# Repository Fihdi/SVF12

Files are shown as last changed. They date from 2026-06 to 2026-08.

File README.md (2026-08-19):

# 8hp 12dB/Oct Voltage Controlled state-variable Filter

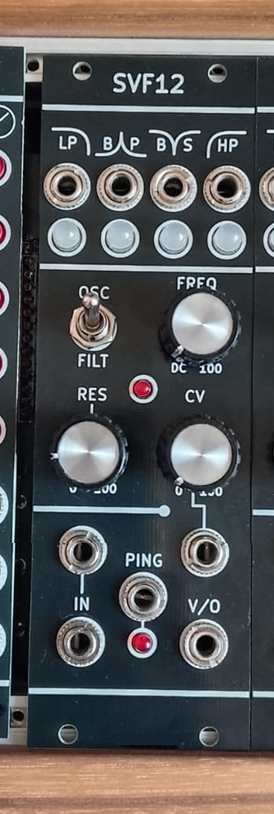
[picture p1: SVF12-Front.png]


# Features
- Two  Inputs **IN** (DC-coupled, allows for audio and CV processing)
- Volt per octave Input **V/O**
- Ping Input **PING**
- Self-Resonance switch **FILT/OSC**
- Lowpass **LP** Bandpass **BP** Bandstop(Notch) **BS** and Highpass **HP** outputs 

# Oscillator mode
The module can be switched from Filter mode (Switch in the **FILT** position) to Oscillator mode (Switch in the **OSC** position), turning the module into a musical sine-cosine quadrature VCO. This can produce clean sine waves on the **BP**, **BS** and **LP** outputs with no input, a mode called self-oscillation. The sinusoidal signals of  **BP** and **HP** are phase-shifted 0, 90 and 180 degrees.

.Inverting the **BP** signal and sending it back into a state variable filter it starts to self-oscillate, albeit with no limiting. Switching from **FILT** to **OSC** changes the **RES** knob from a variable voltage divider to an attenuverter with diode-clipping. With a trimmer on the back of the module, the **V/O** input can be tuned to allow for volt per octave tracking

# Ping Input
By sending a rising-edge signal like a Gate or a short Pulse to the **PING** input, the filter core gets excited and creates a damped oscillation. The length of this oscillation is controlled by the resonance (**RES**) setting.

# Power
A standard 10-pin Eurorack power connector is used (Red Stripe indicates -12V (negative twelve volts)). The module is internally running on +/-9V to stabilise the volt per octave tracking.

# Sponsor
A big Thank You to [PCBWay](https://www.pcbway.com) for sponsoring the development and prototyping of this module! They have excellent build quality and I can recommend using their service to build your own projects! I used the "Black" soldermask and white silkscreen and the surface has very deep and glossy black finish.

Simply upload the Gerber and production files for the B-Board and 90% of the circuitry is done. Solder the final through-hole components and tightend the screws and you have a finished Eurorack module, ready to give your sounds a crunchy filter effect.



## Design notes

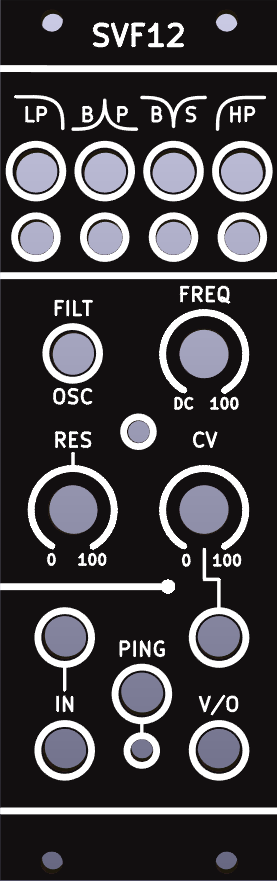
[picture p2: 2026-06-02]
SVF12Front.png

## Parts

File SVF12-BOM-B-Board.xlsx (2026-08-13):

 |  |  | SVF12 B-Board BOM
Item # | *Designator | *Qty | Manufacturer | *Mfg Part # | Description / Value | *Package/Footprint | Type | Your Instructions / Notes
1 | C1,C2 | 2 |  | C107193 | 220pF | Capacitor_SMD:C_1206_3216Metric
2 | C3,C5 | 2 |  | C309030 | 100n | Capacitor_SMD:C_1206_3216Metric
3 | C7 | 1 |  | C5137623 | 10n | Capacitor_SMD:C_1206_3216Metric
4 | C101,C102,C103,C104 | 4 |  | C9807 | 10u | Capacitor_SMD:C_1206_3216Metric
5 | D2,D3,D4 | 3 |  | C917117 | 1N4148 | Diode_SMD:D_SOD-323_HandSoldering
6 | D5,D6 | 2 |  |  | LED | LED_THT:LED_D3.0mm |  | DNP
7 | J2 | 1 |  |  | Conn_02x05_Odd_Even | Connector_IDC:IDC-Header_2x05_P2.54mm_Vertical |  | DNP
8 | J101 | 1 |  |  | Conn_01x09_Pin | Connector_PinHeader_2.54mm:PinHeader_1x09_P2.54mm_Vertical |  | DNP
9 | J104 | 1 |  |  | Conn_01x08_Pin | Connector_PinSocket_2.54mm:PinSocket_1x08_P2.54mm_Vertical |  | DNP
10 | Q1,Q2 | 2 |  | C148244 | BC857 | Package_TO_SOT_SMD:SOT-23-3
11 | Q3 | 1 |  | C475630 | BC847 | Package_TO_SOT_SMD:SOT-23
12 | R1,R4,R5,R6,R7,R8,R10,R14,R16,R18,R28,R29,R31,R34,R35,R42 | 16 |  | C2907421 | 100k | Resistor_SMD:R_1206_3216Metric
13 | R9,R19 | 2 |  | C706444 | 200k | Resistor_SMD:R_1206_3216Metric
14 | R11,R17,R21,R32,R33,R101,R104 | 7 |  | C131398 | 1k | Resistor_SMD:R_1206_3216Metric
15 | R12,R15,R22 | 3 |  | C2930413 | 2k2 | Resistor_SMD:R_1206_3216Metric
16 | R20 | 1 |  | C2907423 | 10k | Resistor_SMD:R_1206_3216Metric
17 | R23 | 1 |  | C2907507 | 47k | Resistor_SMD:R_1206_3216Metric
18 | R102,R103 | 2 |  | C4299795 | 6k2 | Resistor_SMD:R_1206_3216Metric
19 | RV4 | 1 |  |  | 100k | Potentiometer_THT:Potentiometer_Bourns_3296W_Vertical |  | DNP
20 | U1,U4 | 2 |  | C12594 | TL074 | Package_SO:SOIC-14_3.9x8.7mm_P1.27mm
21 | U5 | 1 |  | C174050 | LM13700 | Package_SO:SOIC-16_3.9x9.9mm_P1.27mm
22 | U101 | 1 |  | C51466 | LM317_SOT-223 | Package_TO_SOT_SMD:SOT-223-3_TabPin2
23 | U102 | 1 |  | C19267471 | LM337_SOT223 | Package_TO_SOT_SMD:SOT-223-3_TabPin2

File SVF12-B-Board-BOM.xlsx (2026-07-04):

 |  |  | SVF12 B-Board BOM
Item # | *Designator | *Qty | Manufacturer | *Mfg Part # | Description / Value | *Package/Footprint | Type | Your Instructions / Notes
1 | C1,C2 | 2 |  | C113905 | 220pF | Capacitor_SMD:C_1206_3216Metric
2 | C3,C4,C5 | 3 |  | C82601 | 100n | Capacitor_SMD:C_1206_3216Metric
3 | C7 | 1 |  | C107192 | 10n | Capacitor_SMD:C_1206_3216Metric
4 | C101,C102,C103,C104 | 4 |  | C9807 | 10u | Capacitor_SMD:C_1206_3216Metric
5 | D2,D3,D4 | 3 |  | C917117 | 1N4148 | Diode_SMD:D_SOD-323_HandSoldering
6 | D5,D6 | 2 |  |  | LED | LED_THT:LED_D3.0mm |  | DNP
7 | J2 | 1 |  |  | Conn_02x05_Odd_Even | Connector_IDC:IDC-Header_2x05_P2.54mm_Vertical |  | DNP
8 | J101 | 1 |  |  | Conn_01x08_Pin | Connector_PinSocket_2.54mm:PinSocket_1x08_P2.54mm_Vertical |  | DNP
9 | J103 | 1 |  |  | Conn_01x09_Pin | Connector_PinHeader_2.54mm:PinHeader_1x09_P2.54mm_Vertical |  | DNP
10 | Q1,Q2 | 2 |  | C148244 | BC857 | Package_TO_SOT_SMD:SOT-23-3
11 | Q3 | 1 |  | C475630 | BC847 | Package_TO_SOT_SMD:SOT-23
12 | R1,R4,R5,R6,R7,R8,R10,R14,R16,R18,R28,R29,R31,R34,R35,R42 | 16 |  | C728669 | 100k | Resistor_SMD:R_1206_3216Metric
13 | R9,R19 | 2 |  | C2907451 | 200k | Resistor_SMD:R_1206_3216Metric
14 | R11,R17,R21,R32,R33,R101,R104 | 7 |  | C131398 | 1k | Resistor_SMD:R_1206_3216Metric
15 | R12,R15,R22 | 3 |  | C2907443 | 2k2 | Resistor_SMD:R_1206_3216Metric
16 | R20 | 1 |  | C136889 | 10k | Resistor_SMD:R_1206_3216Metric
17 | R23 | 1 |  | C870758 | 47k | Resistor_SMD:R_1206_3216Metric
18 | R102,R103 | 2 |  | C4299795 | 6k2 | Resistor_SMD:R_1206_3216Metric
19 | RV4 | 1 |  |  | 100k | Potentiometer_THT:Potentiometer_Bourns_3296W_Vertical |  | DNP
20 | U1,U3,U4 | 3 |  | C12594 | TL074 | Package_SO:SOIC-14_3.9x8.7mm_P1.27mm
21 | U5 | 1 |  | C174050 | LM13700 | Package_SO:SOIC-16_3.9x9.9mm_P1.27mm
22 | U101 | 1 |  | C51466 | LM317_SOT-223 | Package_TO_SOT_SMD:SOT-223-3_TabPin2
23 | U102 | 1 |  | C19267471 | LM337_SOT223 | Package_TO_SOT_SMD:SOT-223-3_TabPin2
Need a quick and accurante quote? Need an efficient production? Please read SMT Ordering Necessary Files & Info in 1 minute. Thank you very much!
Click for Instructions on How to Create a BOM (https://www.pcbway.com/blog/PCB_Assembly/How_to_Build_a_BOM__Bill_Of_Materials_.html)

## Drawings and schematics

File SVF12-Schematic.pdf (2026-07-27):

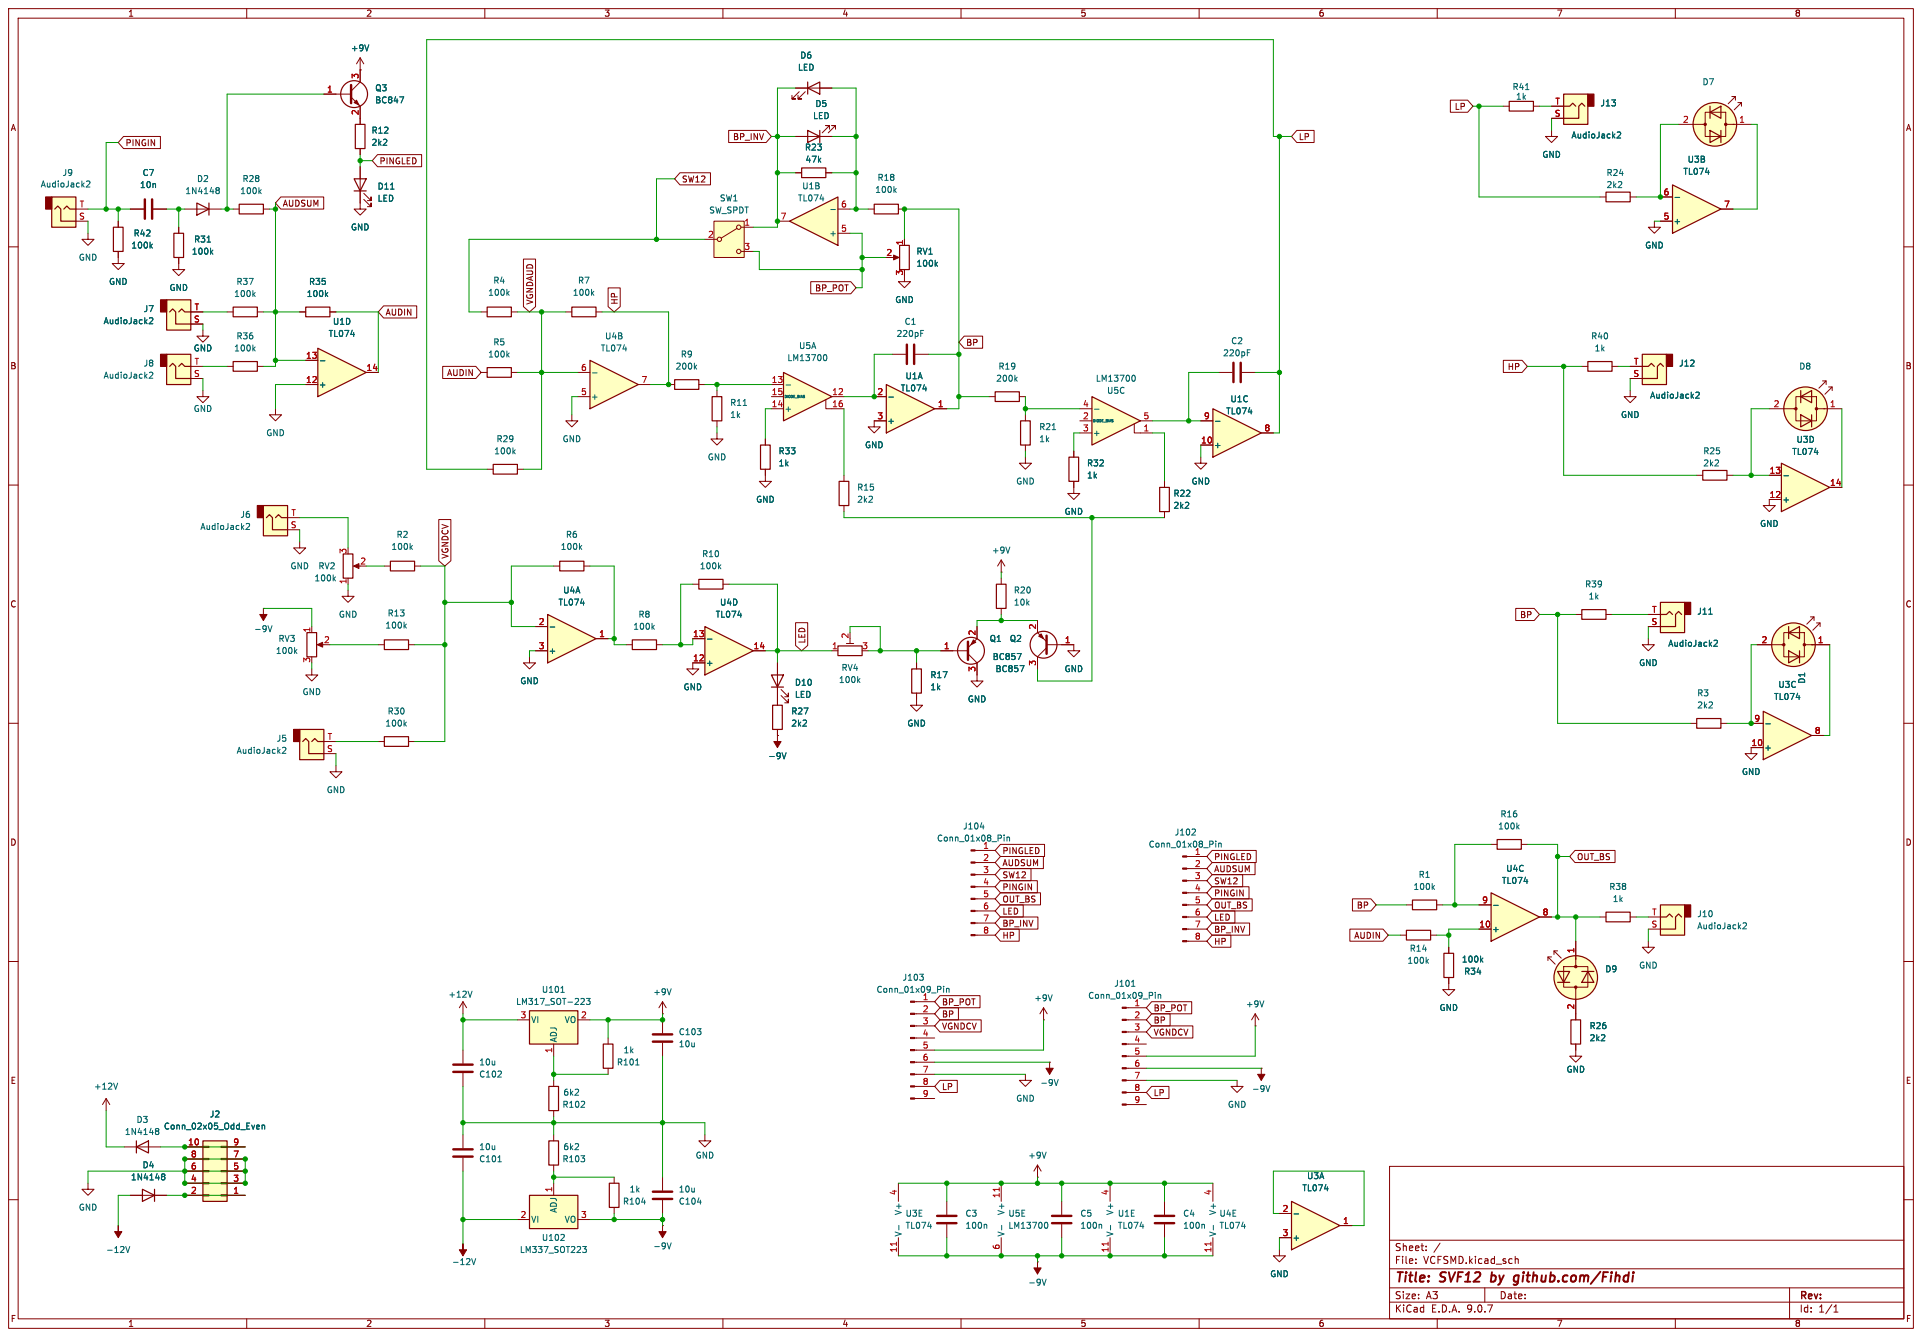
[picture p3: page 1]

Id: 1/1 Title: SVF12 by github.com/Fihdi File: VCFSMD.kicad_sch Sheet: / GND

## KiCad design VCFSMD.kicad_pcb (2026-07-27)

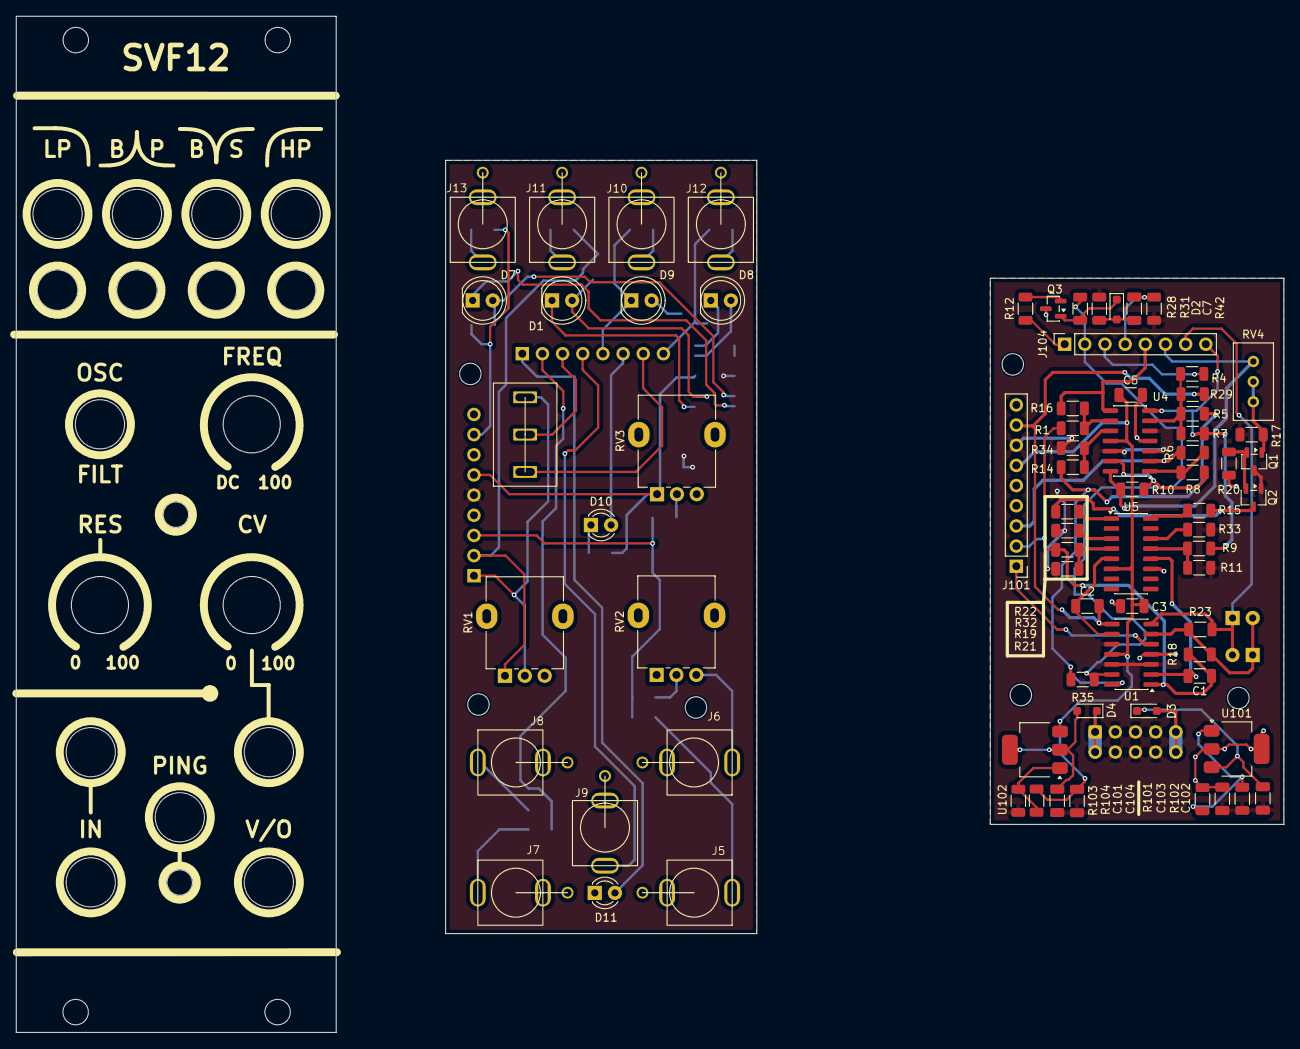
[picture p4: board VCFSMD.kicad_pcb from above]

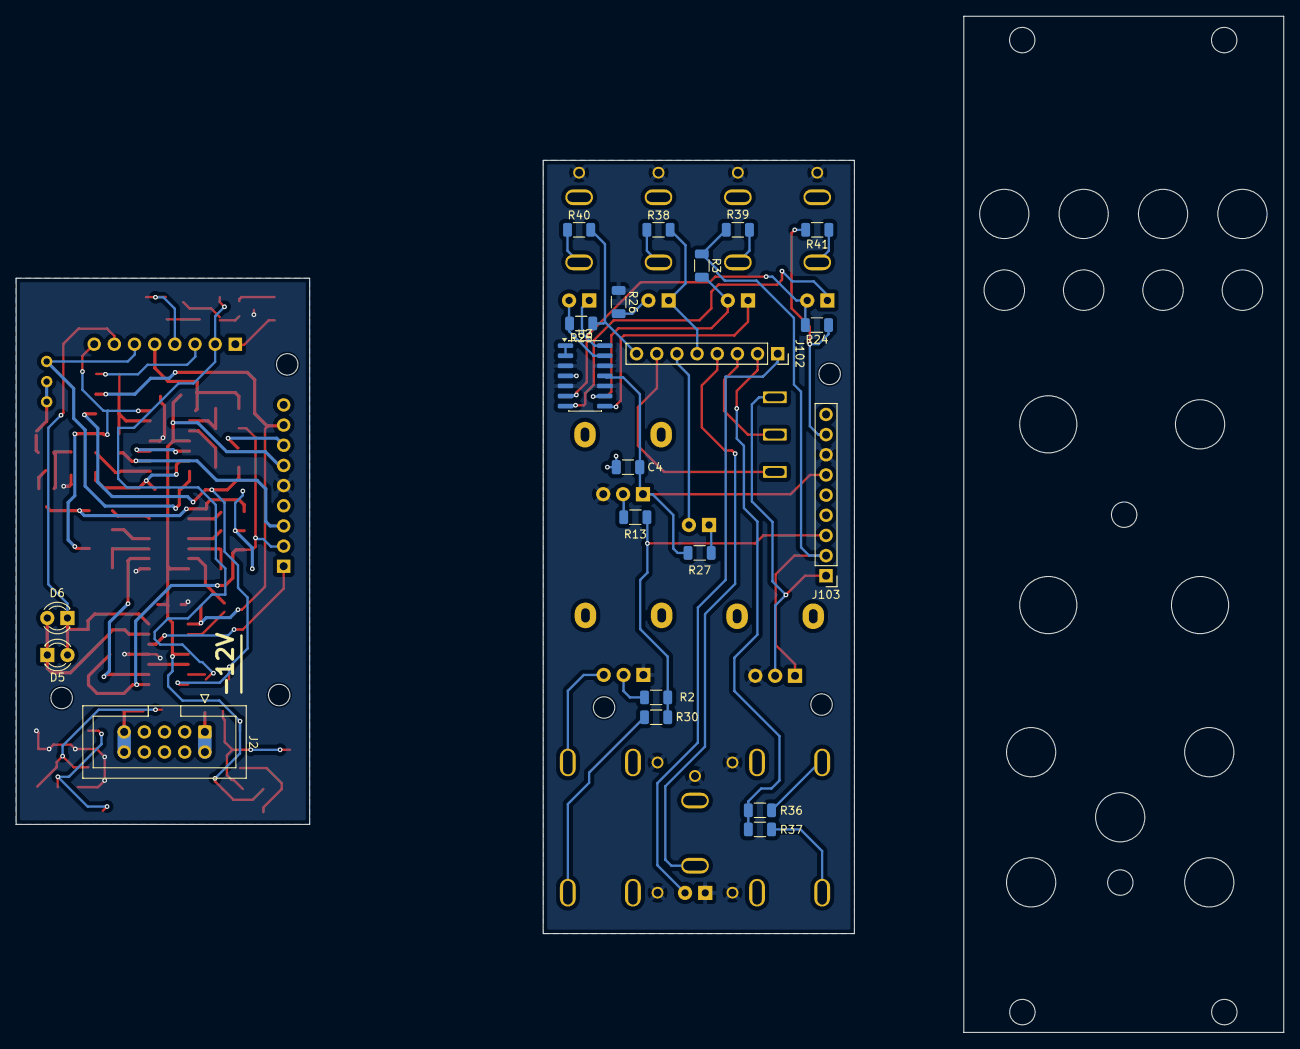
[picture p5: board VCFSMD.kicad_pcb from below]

Board: 2 copper layers, 159.7 x 128.0 mm, 95 parts (21 on the bottom side), 61 nets.

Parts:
C1, C2: 220pF; C_1206_3216Metric
C3, C4, C5: 100n; C_1206_3216Metric
C7: 10n; C_1206_3216Metric
C101, C102, C103, C104: 10u; C_1206_3216Metric
D1, D7, D8, D9: LED_Dual_Bidirectional; LED_D5.0mm
D2, D3, D4: 1N4148; D_SOD-323_HandSoldering
D5, D6, D10, D11: LED; LED_D3.0mm
J2: Conn_02x05_Odd_Even; IDC-Header_2x05_P2.54mm_Vertical
J5, J6, J7, J8, J9, J10, J11, J12, J13: AudioJack2; MonoTRS
J101, J103: Conn_01x09_Pin; PinHeader_1x09_P2.54mm_Vertical
J102, J104: Conn_01x08_Pin; PinSocket_1x08_P2.54mm_Vertical
Q1, Q2: BC857; SOT-23-3
Q3: BC847; SOT-23
R1, R2, R4, R5, R6, R7, R8, R10, R13, R14, R16, R18, R28, R29, R30, R31, R34, R35, R36, R37, R42: 100k; R_1206_3216Metric
R3, R12, R15, R22, R24, R25, R26, R27: 2k2; R_1206_3216Metric
R9, R19: 200k; R_1206_3216Metric
R11, R17, R21, R32, R33, R38, R39, R40, R41, R101, R104: 1k; R_1206_3216Metric
R20: 10k; R_1206_3216Metric
R23: 47k; R_1206_3216Metric
R102, R103: 6k2; R_1206_3216Metric
RV1, RV2, RV3: 100k; Potentiometer_Alpha_RD901F-40-00D_Single_Vertical
RV4: 100k; Potentiometer_Bourns_3296W_Vertical
SW1: SW_SPDT; Switch
U1, U3, U4: TL074; SOIC-14_3.9x8.7mm_P1.27mm
U5: LM13700; SOIC-16_3.9x9.9mm_P1.27mm
U101: LM317_SOT-223; SOT-223-3_TabPin2
U102: LM337_SOT223; SOT-223-3_TabPin2

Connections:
+9V: C3.2, C4.2, C5.2, C103.1, J101.5, J103.5, Q3.3 (C), R20.2, R101.1, U1.4 (V+), U3.4 (V+), U4.4 (V+), U5.11 (V+), U101.2 (VO)
+12V: C102.2, D3.1 (K), U101.3 (VI)
-9V: C3.1, C4.1, C5.1, C104.1, J101.6, J103.6, R27.1, R104.2, RV3.1, U1.11 (V-), U3.11 (V-), U4.11 (V-), U5.6 (V-), U102.3 (VO)
-12V: C101.1, D4.2 (A), U102.2 (VI)
AUDIN: R5.1, R14.2, R35.1, U1.14
AUDSUM: J102.2, J104.2, R28.2, R35.2, R36.1, R37.1, U1.13 (-)
BP: C1.2, J101.2, J103.2, R1.2, R3.1, R18.2, R19.1, R39.2, RV1.1, U1.1
BP_INV: D5.2 (A), D6.1 (K), J102.7, J104.7, R23.1, SW1.1 (A), U1.7
BP_POT: J101.1, J103.1, RV1.2, SW1.3 (C), U1.5 (+)
GND: C101.2, C102.1, C103.2, C104.2, D11.1 (K), J2.3, J2.4, J2.5, J2.6, J2.7, J2.8, J5.S, J6.S, J7.S, J8.S, J9.S, J10.S, J11.S, J12.S, J13.S, J101.7, J103.7, Q1.3 (C), Q2.1 (B), R11.1, R17.1, R21.1, R26.1, R31.2, R32.1, R33.1, R34.2, R42.2, R102.2, R103.1, RV1.3, RV2.1, RV3.3, U1.3 (+), U1.10 (+), U1.12 (+), U3.3 (+), U3.5 (+), U3.10 (+), U3.12 (+), U4.3 (+), U4.5 (+), U4.12 (+)
HP: J102.8, J104.8, R7.2, R9.1, R25.1, R40.2, U4.7
LED: D10.2 (A), J102.6, J104.6, R10.2, RV4.1, U4.14
LP: C2.2, J101.8, J103.8, R24.1, R29.1, R41.2, U1.8
unnamed: D1.2 (AK), R3.2, U3.9 (-)
unnamed: D1.1 (KA), U3.8
unnamed: C7.1, D2.2 (A), R31.1
unnamed: D2.1 (K), Q3.1 (B), R28.1
unnamed: D3.2 (A), J2.9, J2.10
unnamed: D4.1 (K), J2.1, J2.2
unnamed: D5.1 (K), D6.2 (A), R18.1, R23.2, U1.6 (-)
unnamed: D7.2 (AK), R24.2, U3.6 (-)
unnamed: D7.1 (KA), U3.7
unnamed: D8.2 (AK), R25.2, U3.13 (-)
unnamed: D8.1 (KA), U3.14
unnamed: D9.2 (AK), R26.2
unnamed: D10.1 (K), R27.2
unnamed: J5.T, R30.1
unnamed: J6.T, RV2.3
unnamed: J7.T, R37.2
unnamed: J8.T, R36.2
unnamed: J10.T, R38.1
unnamed: J11.T, R39.1
unnamed: J12.T, R40.1
unnamed: J13.T, R41.1
unnamed: Q1.1 (B), R17.2, RV4.2, RV4.3
unnamed: Q1.2 (E), Q2.2 (E), R20.1
unnamed: Q2.3 (C), R15.1, R22.1
unnamed: Q3.2 (E), R12.2
unnamed: R2.1, RV2.2
unnamed: R6.2, R8.1, U4.1
unnamed: R13.1, RV3.2
unnamed: R15.2, U5.16
unnamed: R22.2, U5.1
unnamed: C1.1, U1.2 (-), U5.12
unnamed: C2.1, U1.9 (-), U5.5
unnamed: U3.1, U3.2 (-)
unnamed: R14.1, R34.1, U4.10 (+)
unnamed: R1.1, R16.2, U4.9 (-)
unnamed: R8.2, R10.1, U4.13 (-)
unnamed: R33.2, U5.14 (+)
unnamed: R9.2, R11.2, U5.13 (-)
unnamed: R32.2, U5.3 (+)
unnamed: R19.2, R21.2, U5.4 (-)
unnamed: R101.2, R102.1, U101.1 (ADJ)
unnamed: R103.2, R104.1, U102.1 (ADJ)
OUT_BS: D9.1 (KA), J102.5, J104.5, R16.1, R38.2, U4.8
PINGIN: C7.2, J9.T, J102.4, J104.4, R42.1
PINGLED: D11.2 (A), J102.1, J104.1, R12.1
SW12: J102.3, J104.3, R4.1, SW1.2 (B)
VGNDAUD: R4.2, R5.2, R7.1, R29.2, U4.6 (-)
VGNDCV: J101.3, J103.3, R2.2, R6.1, R13.2, R30.2, U4.2 (-)

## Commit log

2026-07-22 Changed mounting holes for spacers from M2 to M2.5
    [VCFSMD.kicad_pcb, VCFSMD.kicad_sch]
2026-07-27 Version 2 with Fixed outputs
    The output buffers were driven into phase reversal at high amplitude. Outputs are taken directly out of the filter core.
    [SVF12-B-Board-BOM.csv, SVF12-BOM-B-Board.xlsx, VCFSMD.kicad_pcb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]
